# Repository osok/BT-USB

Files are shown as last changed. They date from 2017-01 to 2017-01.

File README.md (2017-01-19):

#Description
I needed a device to be plugged into a USB port only when I wanted it to be, but I could not gain access to it or the USB port physically, I could only gain general proximity to it.

#Board Manufacturing
OSHPark, https://oshpark.com/, can be used to fabricate the board.  Simply upload the "BT USB All SMD.brd" and select how many you would like to have built.  OSHPak takes about 2 to 3 weeks to fabricate the board.  You will have to purchase 3 at a time.  When I last ordered the board it was $9.95 for 3.

A Stencil to mask solder paste can be create by uploading the "BT USB All SMD.brd" to OSHStencils, https://www.oshstencils.com/.

#Components
* RF22301, these cost about $20
* USB In
* USB Out
* EE2-3NUX I purchased mine from eBay for about $0.50 each.
* AMS1117 voltage regulator, cost about $1
* Pin headers for UART I had some laying around

As for the smd components I picked up some sample books of capacitors, transistors, resistors, diodes and the such with a verity of components from eBay.  So for me these pieces were less than a penny each.

# Note
Once you solder the RF22301 on to a board its there.  I have not been able to remove one from an old board.  

#Operation
I used nRF Connect, that I downloaded from the Google Play to connect and trigger the switch.

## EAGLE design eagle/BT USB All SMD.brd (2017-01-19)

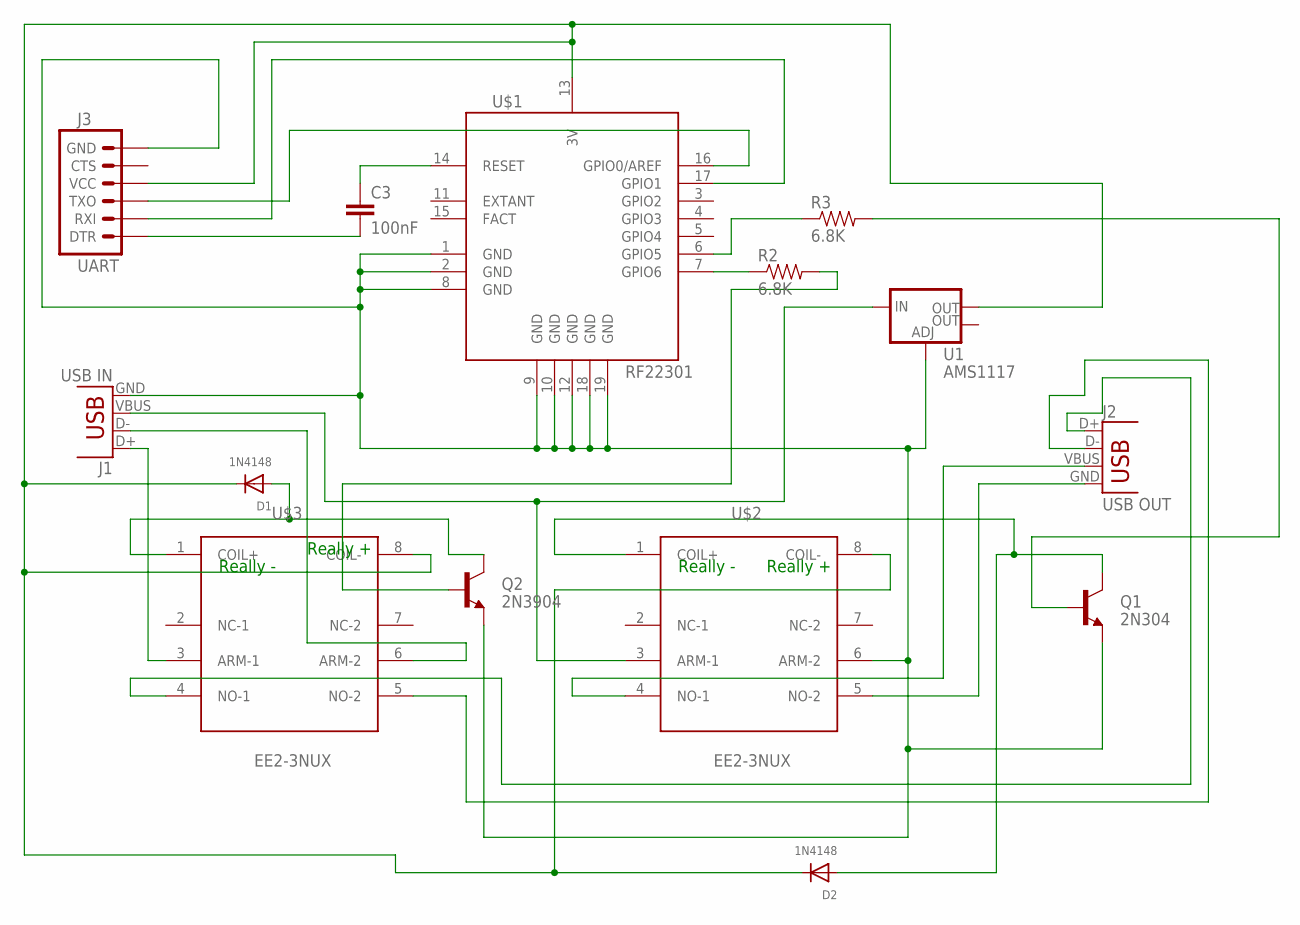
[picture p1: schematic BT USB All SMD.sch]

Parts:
C3: 100nF; 0805
D1, D2: 1N4148; SOD-123
J1: USB IN; USB-A-H
J2: USB OUT; USB-A-S
J3: UART; 1X06
Q1: 2N304; SOT23-3
Q2: 2N3904; SOT23-3
R2, R3: 6.8K; 0805
U1: AMS1117; SOT223
U$1: RF22301; RFD22301
U$2, U$3: RELAY-EE2-3NUX

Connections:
D_HIGH: J1.D+, U$3.3 (ARM-1)
D_HIGH_OUT: J2.D+, U$3.4 (NO-1)
D_LOW: J1.D-, U$3.6 (ARM-2)
D_LOW_OUT: J2.D-, U$3.5 (NO-2)
GND: J1.GND, J3.6 (GND), Q1.2 (E), Q2.2 (E), U1.1 (ADJ), U$1.1 (GND), U$1.2 (GND), U$1.8 (GND), U$1.9 (GND), U$1.10 (GND), U$1.12 (GND), U$1.18 (GND), U$1.19 (GND), U$2.6 (ARM-2)
GND_OUT: J2.GND, U$2.5 (NO-2)
unnamed: D1.A, Q2.3 (C), U$3.1 (COIL+)
unnamed: D2.A, Q1.3 (C), U$2.1 (COIL+)
unnamed: C3.1, U$1.14 (RESET)
unnamed: C3.2, J3.1 (DTR)
unnamed: J3.3 (TXO), U$1.16 (GPIO0/AREF)
unnamed: J3.2 (RXI), U$1.17 (GPIO1)
unnamed: Q2.1 (B), R2.2
unnamed: R2.1, U$1.7 (GPIO6)
unnamed: R3.1, U$1.6 (GPIO5)
unnamed: Q1.1 (B), R3.2
V3_3: D1.C, D2.C, J3.4 (VCC), U1.2 (OUT), U$1.13 (3V), U$2.8 (COIL-), U$3.8 (COIL-)
V5_0: J1.VBUS, U1.3 (IN), U$2.3 (ARM-1)
V5_0_OUT: J2.VBUS, U$2.4 (NO-1)

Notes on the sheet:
Really +
Really -

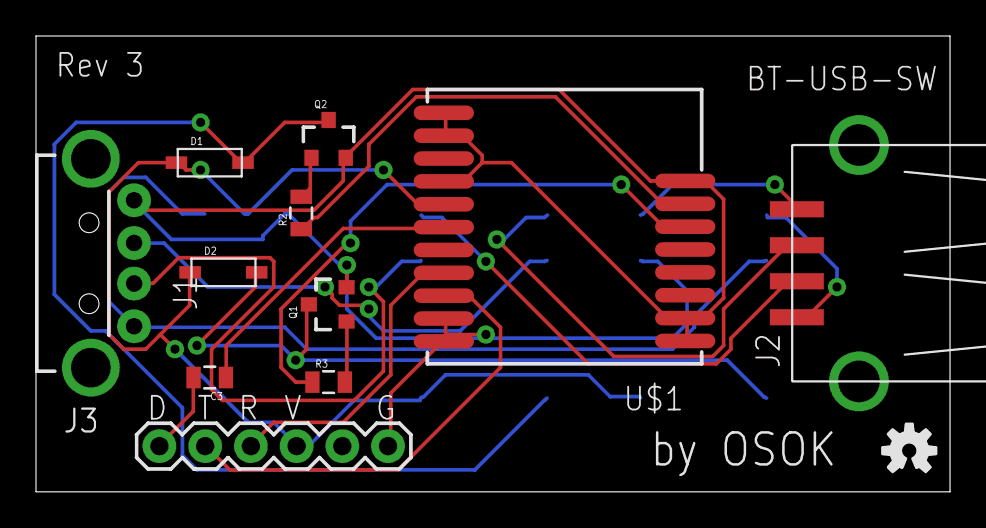
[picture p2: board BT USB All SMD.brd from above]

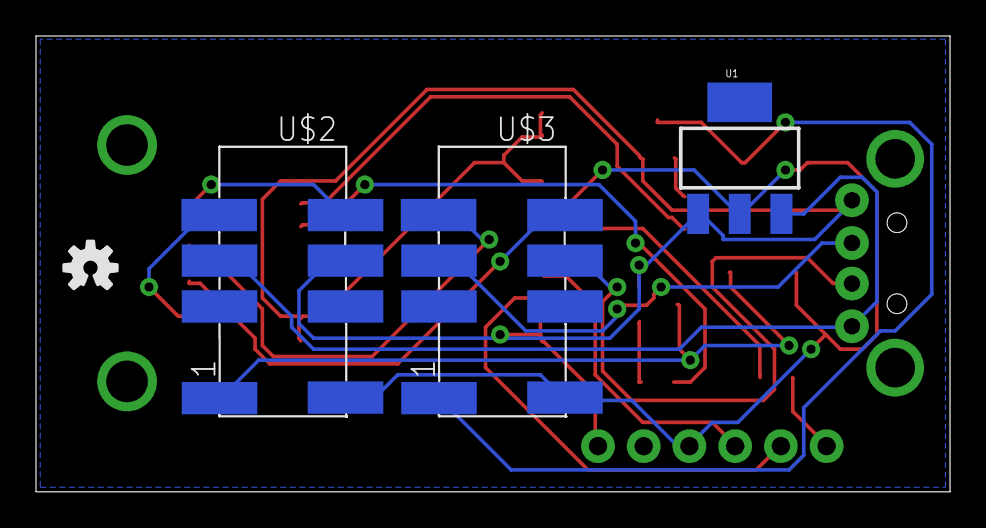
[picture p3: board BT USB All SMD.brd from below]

Board: 2 copper layers, 50.8 x 25.3 mm, 16 parts (4 on the bottom side), 19 nets.

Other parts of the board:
U$4, U$5: OSHW-LOGO-S

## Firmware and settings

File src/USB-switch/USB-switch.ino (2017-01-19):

/*
This RFduino sketch demonstrates a full bi-directional Bluetooth Low
Energy 4 connection between an iPhone application and an RFduino.
This sketch also demonstrates how to select a slower connection
interval, which will slow down the response rate, but also drastically
reduce the power consumption of the RFduino.

This sketch works with the rfduinoLedButton iPhone application.

The button on the iPhone can be used to turn the green led on or off.
The button state of button 1 is transmitted to the iPhone and shown in
the application.
*/

/*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
 THE SOFTWARE IS PROVIDED "AS IS", WITHOUT WARRANTY OF ANY KIND,
 EXPRESS OR IMPLIED, INCLUDING BUT NOT LIMITED TO THE WARRANTIES OF
 MERCHANTABILITY, FITNESS FOR A PARTICULAR PURPOSE AND NONINFRINGEMENT.
 IN NO EVENT SHALL THE AUTHORS OR COPYRIGHT HOLDERS BE LIABLE FOR ANY
 CLAIM, DAMAGES OR OTHER LIABILITY, WHETHER IN AN ACTION OF CONTRACT,
 TORT OR OTHERWISE, ARISING FROM, OUT OF OR IN CONNECTION WITH THE
 SOFTWARE OR THE USE OR OTHER DEALINGS IN THE SOFTWARE.
*/

#include <RFduinoBLE.h>

int relay_1 = 5;
int relay_2 = 6;


void switchRelay(bool isOn){
  Serial.print("Switch " );
  Serial.println(isOn?"on":"off");
     digitalWrite(relay_1, isOn?HIGH:LOW);
    digitalWrite(relay_2, isOn?HIGH:LOW);
}

void setup() {
  Serial.begin(9600);
  
  Serial.println("Starting...");
  
  // led turned on/off from the iPhone app
  pinMode(relay_1, OUTPUT);
  pinMode(relay_2, OUTPUT);

 
  // this is the data we want to appear in the advertisement
  // (if the deviceName and advertisementData are too long to fix into the 31 byte
  // ble advertisement packet, then the advertisementData is truncated first down to
  // a single byte, then it will truncate the deviceName)
  RFduinoBLE.advertisementData = "USB-Switch";
  
  // start the BLE stack
  RFduinoBLE.begin();
  Serial.println("Bluetooth on");
  switchRelay(false);
}





void loop() {
//  delay_until_button(HIGH);
//  RFduinoBLE.send(1);
//  
//  delay_until_button(LOW);
//  RFduinoBLE.send(0);

  // uncomment here to update the connection interval after the first button press  
  // RFduinoBLE_update_conn_interval(900,1000);
  
  // display the connection interval the iPhone actually selected after a button press
}


void RFduinoBLE_onConnect()
{
  // request central role use a different connection interval in the given range
  // the central role may reject the request (or even pick a value outside the range)
  // we will request something in the 900ms to 1100ms range
  // the actual rate the iPhone uses is 1098ms
  // the best way to get the connection interval you are after is trail and error
  // if the iPhone rejects the request, the connection interval will be the default (25ms)
  RFduinoBLE.updateConnInterval(900, 1100);
  Serial.println("Bluetooth onConnect()");

  // note: you cannot use delay()/RFduinoBLE.getConnInterval() here to determine which
  // connection interval the iPhone selected - getConnInterval() must be called from
  // either loop() or onReceive()
}

void RFduinoBLE_onDisconnect()
{
  Serial.println("Bluetooth onDisconnect()");

}

void RFduinoBLE_onReceive(char *data, int len)
{
  Serial.println("Bluetooth onReceive()");
  // display the connection interval the iPhone actually selected after a button press
  int connInterval = RFduinoBLE.getConnInterval();
  Serial.println(connInterval);
  
  // if the first byte is 0x01 / on / true
  if (data[0]){
    switchRelay(true);
  } else{
    switchRelay(false);
  }
    
}

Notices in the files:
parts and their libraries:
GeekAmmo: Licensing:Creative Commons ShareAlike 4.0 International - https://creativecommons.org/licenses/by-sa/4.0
